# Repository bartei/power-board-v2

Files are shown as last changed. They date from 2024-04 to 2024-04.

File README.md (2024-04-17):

# Raspberry Power Board

This simple power board is used in conjunction with the rotary-controller board. It provides a reliable power source for the Raspberry Pi and additionally it includes an RS485 interface
chip which allows easy communication with any external RS485 device.

The UART to RS485 converter chip is powered by the 3.3v generated by the Raspberry.
A few convenient LEDs provide some status information about the power supplies and the communication activity detected on the RS485 TX line coming from the SBC.

When powering up the board without an SBC connected to it, only the 5V status LED will power up.

This power board should be able to provide enough power for the SBC, a display, and a few external devices.

The board can be powered with an AC/DC power supply, making it easy to use with an old school transformer (24VAC max recommended) or any DC power supply (10-36V recommended).

Efficiency and absolute maximum ratins will vary depending on the provided power supply voltage, the selected coil is most efficient when working around 12-18 volts.

When powering the board with a DC power supply, polarity is not relevant, making it harder to make mistakes.

Some basic circuit protection is provided by means of ESD diodes and a resettable fuse.

The selected SR485 interface chip is compatible with 3V3 signals (same as the SBC) and it includes ESD protection, making it a simple choice for interfacing with external devices without
many extra components.

When connecting the serial line with long distance wires make sure to properly select a termination resistor in your line and ensure also that proper biasing resistors are placed 
in order to maximize compatibility with 3rd party serial devices. 330 Ohm resistors are commonly used for line biasing, whereas 120 Ohm are generally used for line termination.

Propoer component selection, especially when dealing with long distances, together with suitable cable selection, are critical for a reliable and fast connection between your devices.

The project includes also suitable production files that are currently being used for manufacturing, if you see mistakes or have ideas that you want to suggest for this project, shoot
me an email: bartei81@gmail.com.

Thanks for your interest in the project!

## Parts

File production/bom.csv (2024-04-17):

Designator | Footprint | Quantity | Value | LCSC Part #
BR1 | SOTFL510P865X150-4N | 1 | MSB40M
C1, C2 | CP_Elec_10x12.6 | 2 | 330u | C128512
C3 | 0805 | 1 | 1u | C24123
D1, D4, D6 | 0603 | 3 | LED | C965799
D2 | D_SMC | 1 | SMDJ40CA | C84730
D5 | D_SMA | 1 | 3A | C8678
F1 | 1812 | 1 | 2A | C960026
H1, H2, H3, H4 | MountingHole_2.7mm_M2.5 | 4 | MountingHole
J1 | PinHeader_2x20_P2.54mm_Vertical | 1 | Raspberry_Pi_2_3
J2 | TerminalBlock_Phoenix_MKDS-1,5-2-5.08_1x02_P5.08mm_Horizontal | 1 | AC Power In
J3 | TerminalBlock_Phoenix_MKDS-1,5-2-5.08_1x02_P5.08mm_Horizontal | 1 | RS485
L1 | L_Sunlord_SWRB1207S | 1 | 47u | C2929503
Q1 | SOT-23 | 1 | BC847 | C181140
Q2, Q3 | SOT-23 | 2 | BC857 | C8666
R1 | 0805 | 1 | 1k5 | C4310
R2, R3, R4, R6 | 0805 | 4 | 6k8 | C17772
R5, R7 | 0805 | 2 | 330 | C17630
U1 | SOP-8_3.9x4.9mm_P1.27mm | 1 | SP3485EEN | C668205
U2 | TO-263-5_TabPin3 | 1 | LM2596S-5 | C347421

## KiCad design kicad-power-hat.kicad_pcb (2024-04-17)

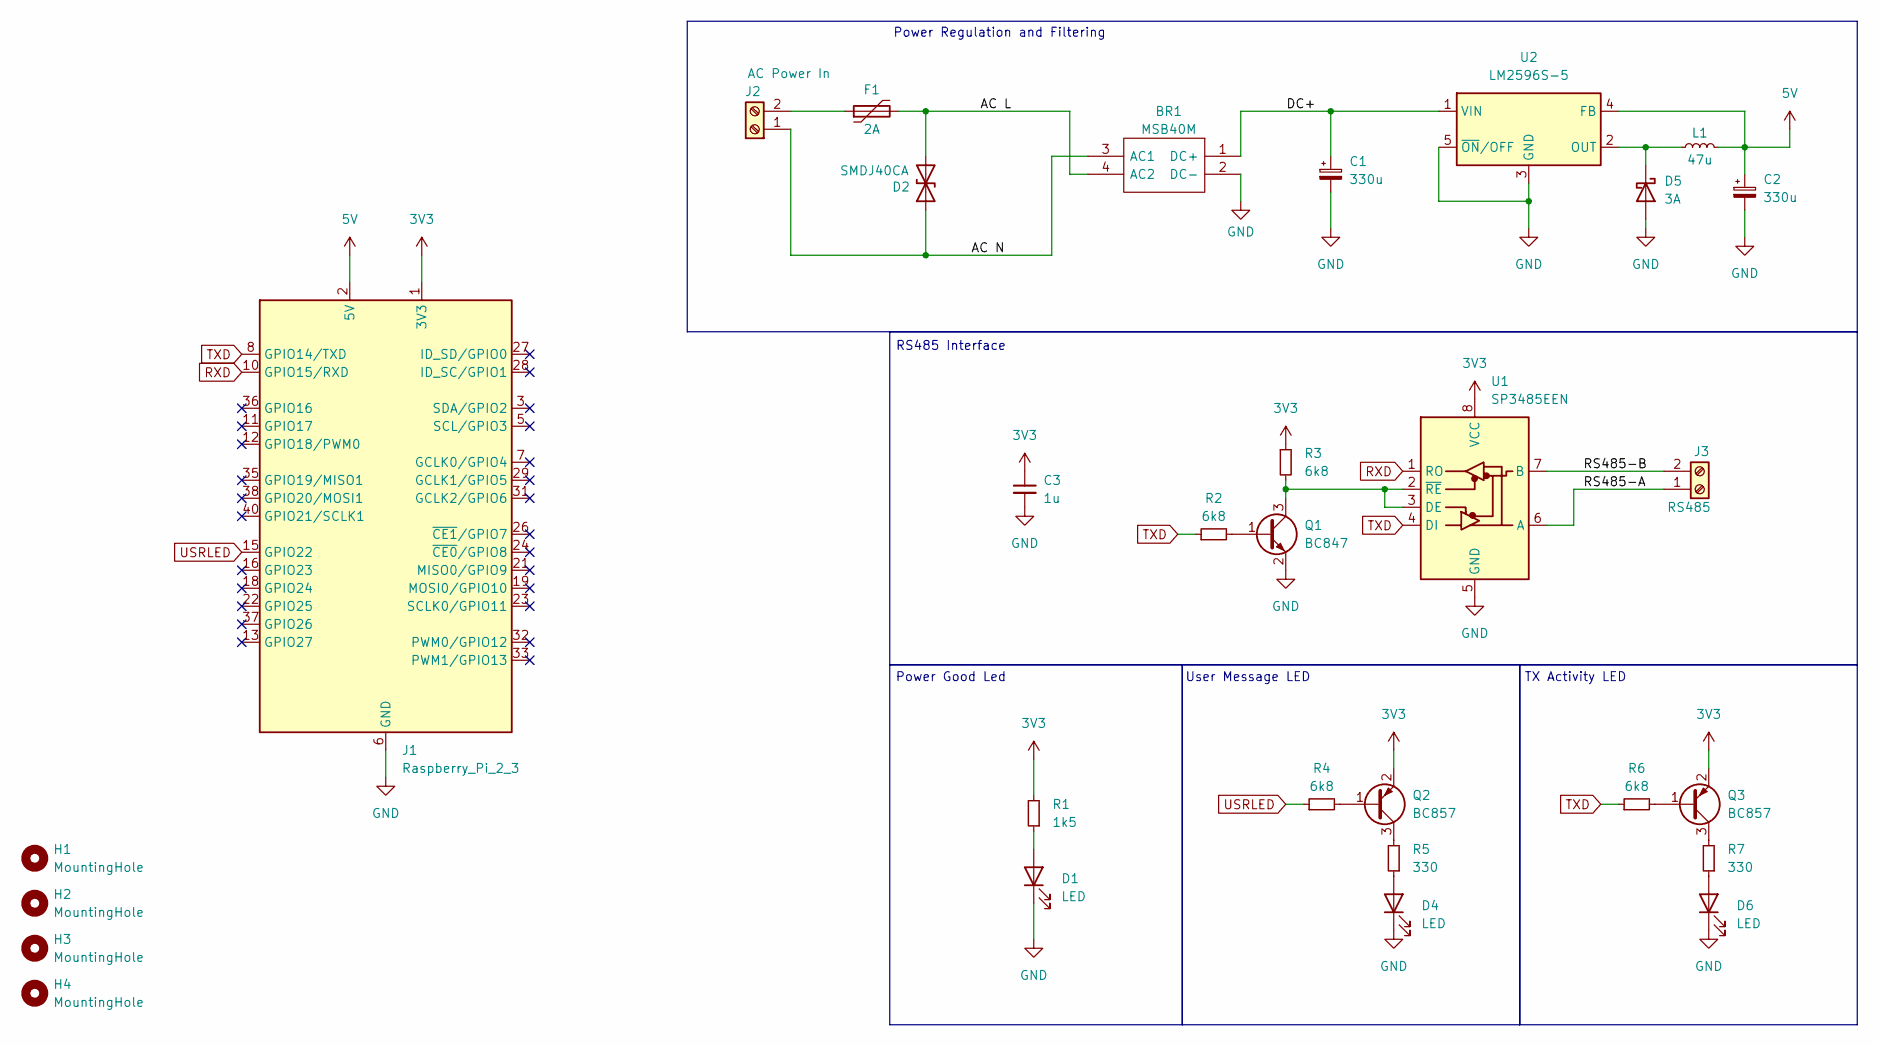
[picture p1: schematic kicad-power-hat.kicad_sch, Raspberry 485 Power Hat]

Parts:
BR1: MSB40M; SOTFL510P865X150-4N; Manufacturer_Part_Number MSB40M
C1, C2: 330u; CP_Elec_10x12.6; LCSC C128512
C3: 1u; C_0805_2012Metric; LCSC C24123
D1, D4, D6: LED; D_0603_1608Metric; LCSC C965799
D2: SMDJ40CA; D_SMC; LCSC C84730
D5: 3A; D_SMA; LCSC C8678
F1: 2A; Fuse_1812_4532Metric; LCSC C960026
H1, H2, H3, H4: MountingHole; MountingHole_2.7mm_M2.5
J1: Raspberry_Pi_2_3; PinHeader_2x20_P2.54mm_Vertical
J2: AC Power In; TerminalBlock_Phoenix_MKDS-1,5-2-5.08_1x02_P5.08mm_Horizont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
J3: RS485; TerminalBlock_Phoenix_MKDS-1,5-2-5.08_1x02_P5.08mm_Horizont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
L1: 47u; L_Sunlord_SWRB1207S; LCSC C2929503
Q1: BC847; SOT-23; LCSC C181140
Q2, Q3: BC857; SOT-23; LCSC C8666
R1: 1k5; R_0805_2012Metric; LCSC C4310
R2, R3, R4, R6: 6k8; R_0805_2012Metric; LCSC C17772
R5, R7: 330; R_0805_2012Metric; LCSC C17630
U1: SP3485EEN; SOP-8_3.9x4.9mm_P1.27mm; LCSC C668205
U2: LM2596S-5; TO-263-5_TabPin3; LCSC C347421

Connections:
3V3: C3.1, J1.1 (3V3), J1.17 (3V3), Q2.2 (E), Q3.2 (E), R1.2, R3.1, U1.8 (VCC)
5V: C2.1, J1.2 (5V), J1.4 (5V), L1.2, U2.4 (FB)
/AC L: BR1.4 (AC2), D2.2 (A2), F1.2
/AC N: BR1.3 (AC1), D2.1 (A1), J2.1
/DC+: BR1.1 (DC+), C1.1, U2.1 (VIN)
/RS485-A: J3.1, U1.6 (A)
/RS485-B: J3.2, U1.7 (B)
GND: BR1.2 (DC-), C1.2, C2.2, C3.2, D1.1 (K), D4.1 (K), D5.2 (A), D6.1 (K), J1.6 (GND), J1.9 (GND), J1.14 (GND), J1.20 (GND), J1.25 (GND), J1.30 (GND), J1.34 (GND), J1.39 (GND), Q1.2 (E), U1.5 (GND), U2.3 (GND), U2.5 (~ON/OFF)
unnamed: D1.2 (A), R1.1
unnamed: D4.2 (A), R5.1
unnamed: D5.1 (K), L1.1, U2.2 (OUT)
unnamed: D6.2 (A), R7.1
unnamed: F1.1, J2.2
unnamed: Q1.1 (B), R2.2
unnamed: Q1.3 (C), R3.2, U1.2 (~RE), U1.3 (DE)
unnamed: Q2.1 (B), R4.2
unnamed: Q2.3 (C), R5.2
unnamed: Q3.1 (B), R6.2
unnamed: Q3.3 (C), R7.2
RXD: J1.10 (GPIO15/RXD), U1.1 (RO)
TXD: J1.8 (GPIO14/TXD), R2.1, R6.1, U1.4 (DI)
USRLED: J1.15 (GPIO22), R4.1

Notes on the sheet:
Power Regulation and Filtering
Power Good Led
TX Activity LED
RS485 Interface
User Message LED

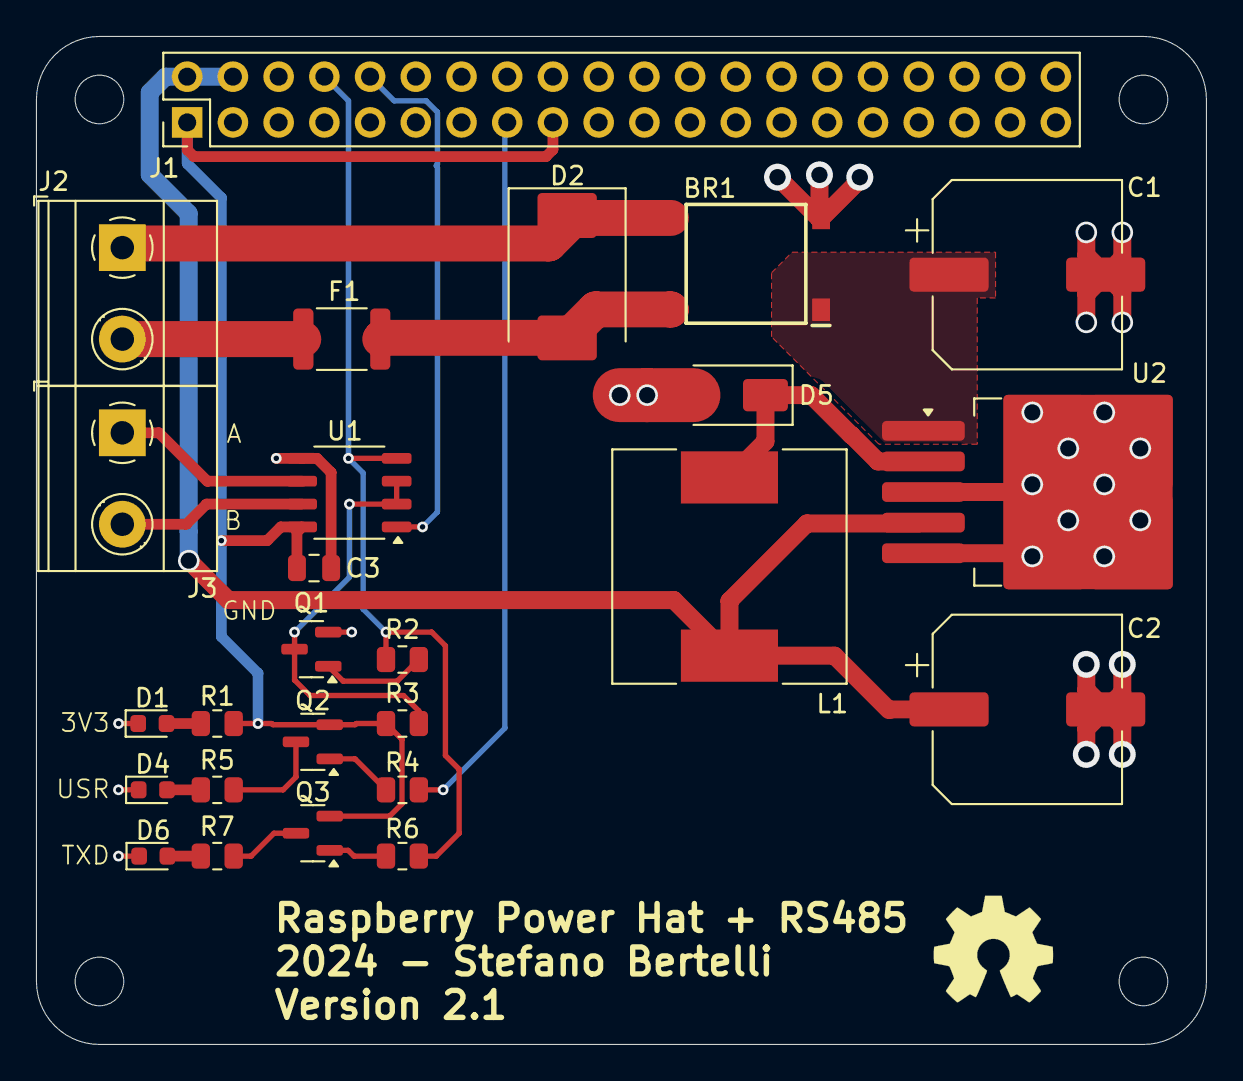
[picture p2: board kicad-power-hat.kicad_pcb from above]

Board: 2 copper layers, 65.0 x 56.0 mm, 30 parts (0 on the bottom side), 22 nets.

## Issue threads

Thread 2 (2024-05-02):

Add support for digital inputs

bartei, 2024-05-02:
Add support for protected digital inputs that can be used for example to read a jog wheel or a push button directly from the raspberry pi.

This feature would allow us to connect physical buttons to the display and allow handling slower speed signals for better control of the DRO boards.

Good also for general purpose IO directly form the Raspberry PI

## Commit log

2024-03-03 wip: update to layout and labels
    [kicad-power-hat.kicad_pcb, kicad-power-hat.kicad_sch]
2024-03-07 Remove output files from root folder
    [kicad-power-hat-B_Cu.gbr, kicad-power-hat-B_Mask.gbr, kicad-power-hat-B_Paste.gbr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]
2024-03-07 Updated pcb
    [bom.csv, designators.csv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]
2024-03-08 fix: cleanup backups and update crowbar diode part number
    [kicad-power-hat.kicad_sch]
2024-04-17 fix: Update holes pattern and footprint for rectifier
    [bom.csv, designators.csv, kicad-power-hat.kicad_pcb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]
